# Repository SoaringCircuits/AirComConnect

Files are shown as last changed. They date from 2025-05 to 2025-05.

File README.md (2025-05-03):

# AirComConnect

board

## General remarks
This small board is designed to simplify and organize the wiring in your glider.
It provides a clean extension point to wire the cables for the AirAvionics AirCom.

## Electrical installation
Installation is easy, but some basic skills in creating cable harnesses are needed to create the connection from AirCom to the board.
The following diagram shows the harness to build to connect S100 and board. 

The board provides terminals for power and common inputs for a double seated glider with dynamic microphones and a speaker.

## D-SUB Connectors
The board uses one D-SUB High Density connector.
I recommend to use connectors with crimped contacts, but solderd ones will work as well.
All connections are direct lines, there is no need to crimp/solder more than one cable to a single contact.

## Wago Terminals
All terminals are easy to operate, just push the actuator with a little screwdriver and push-in or pull-out the conductor.

The terminals for fuses and devices are suitable for various types of wires:
- Solid concductor 0.2 - 1.5 mm^2
- Fine-stranded conductor 0.2 - 1.5 mm^2
- Fine-stranded conductor with ferrule 0.25 - 1.0 mm^2

The terminal for the main supply can handle conductors up to:
- Solid concductor 0.1 - 4.0 mm^2
- Fine-stranded conductor 0.1 - 4.0 mm^2
- Fine-stranded conductor with ferrule 0.25 - 2.5 mm^2

## Mechanical installation
The half housing is 3D-printed and reliably protects against short circuits on the contacts on the underside of the board.
With four mounting holes for M3 screws, the board can be securely and firmly mounted in the aircraft, with the screws fixing both the housing and the board at the same time.

## Disclaimer
Installation and use of the board are the sole responsibility of the user.
AirAvionics, the manufacturer of the AirCom, is and was NOT involved in the development of the board and can not be hold responsibly for any failures or damage to the device.
The board has been built to the best of my knowledge and belief, but no warranty or guarantee can be given for correct functioning or interference immunity.
The legal usability must be checked before each individual installation and, in case of doubt, clarified with competent and authorized personnel (CFS).

## Licence
Copyright Fabian Schöttler 2025.

This source describes Open Hardware and is licensed under the CERN-OHL-P
v2 or later.

You may redistribute and modify this documentation and make products
using it under the terms of the CERN-OHL-P v2 or later (https:/cern.ch/cern-ohl).
This documentation is distributed WITHOUT ANY EXPRESS OR IMPLIED
WARRANTY, INCLUDING OF MERCHANTABILITY, SATISFACTORY QUALITY
AND FITNESS FOR A PARTICULAR PURPOSE.
Please see the CERN-OHL-P v2 for applicable conditions

## Contact
If you have any questions or suggestions about the board, please send an e-mail to fabian@schoettlerhome.de.

------
Electrical, PCB and case design by [ScotteC](https://github.com/ScotteC)

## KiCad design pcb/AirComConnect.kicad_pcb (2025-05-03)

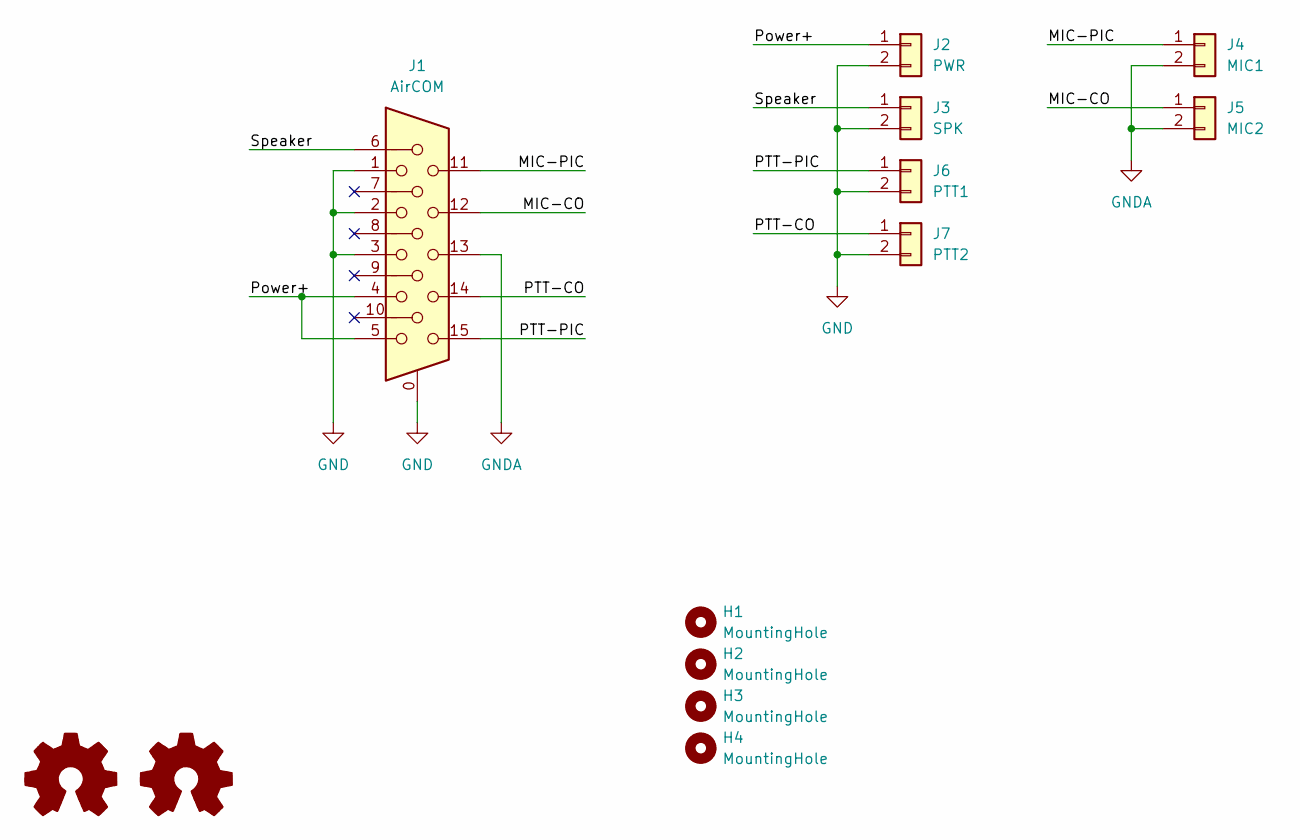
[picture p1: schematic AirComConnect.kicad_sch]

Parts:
H1, H2, H3, H4: MountingHole; MountingHole_3.2mm_M3
J1: AirCOM; DSUB-15-HD_Socket_Vertical_P2.29x1.98mm_MountingHoles
J2: PWR; Wago-250-202
J3: SPK; Wago-250-202
J4: MIC1; Wago-250-202
J5: MIC2; Wago-250-202
J6: PTT1; Wago-250-202
J7: PTT2; Wago-250-202

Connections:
/MIC-CO: J1.12, J5.1
/MIC-PIC: J1.11, J4.1
/PTT-CO: J1.14, J7.1
/PTT-PIC: J1.15, J6.1
/Power+: J1.4, J1.5, J2.1
/Speaker: J1.6, J3.1
GND: J1.0, J1.1, J1.2, J1.3, J2.2, J3.2, J6.2, J7.2
GNDA: J1.13, J4.2, J5.2

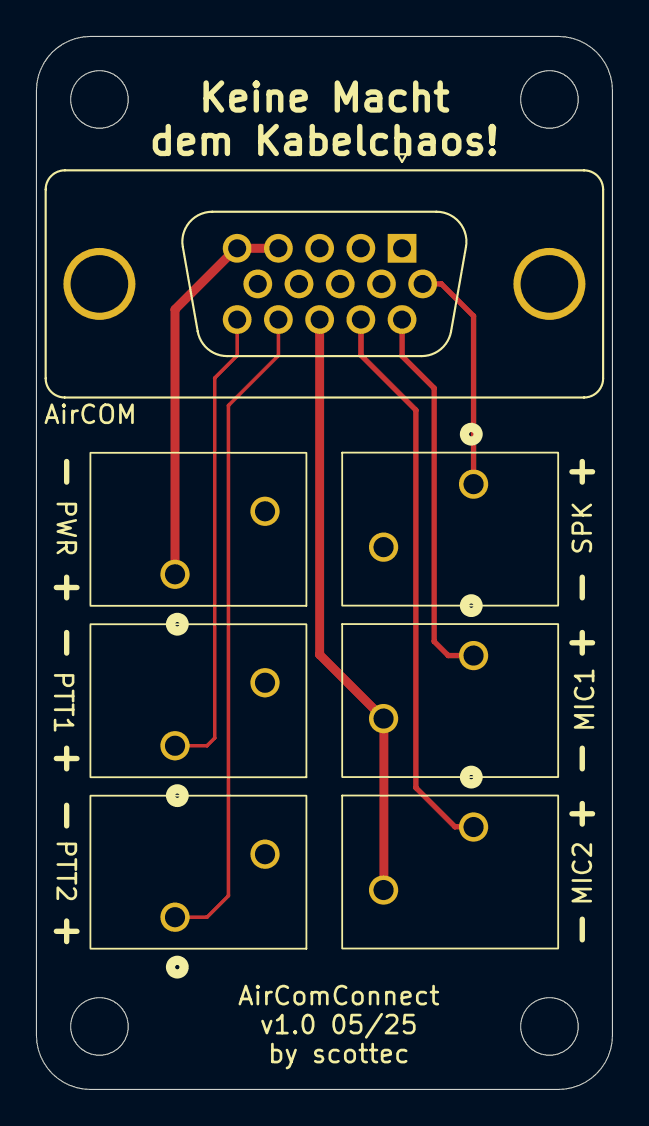
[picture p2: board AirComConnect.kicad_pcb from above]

Board: 2 copper layers, 32.0 x 58.5 mm, 11 parts (0 on the bottom side), 8 nets.
